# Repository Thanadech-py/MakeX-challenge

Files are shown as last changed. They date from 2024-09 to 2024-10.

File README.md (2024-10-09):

<h1 align="center">GravityShift</h1>
<h2>Code Of GravityShift Team</h2>
<p>
  This Respirotory is use for store and publish the code and CAD file of team for education and competion
</p> 

<h2>Teammate</h2>

- Thanadech Lapassirikul : Head-Programmer, Technicain, Main-Electical and Subport-Machanical
  
  Contact : [IG: Thanadech.py](https://www.instagram.com/thxncdzch.py/)
- Tanapat Pinnok : Head-Machanical, Subport-Electrical, Pilot and Quality Check

  Contact : [IG: zu.seven](https://www.instagram.com/zu.seven/)
- Natdanai duangraksa : Head-Designer and Subport-Machanical

  Contact : [IG: peanaatbattaa](https://www.instagram.com/nomchocolatemaiwan/)
- Pranutsma Khwanrueang : Suport-Designer, Copilot and Team Planer

  Contact : [IG: tgzee_](https://www.instagram.com/tgzee._/)

<h3>The link to the Document for MakeX Challenge Competition</h3>

- [MicroPython For NovaPI](https://github.com/Makeblock-official/micropython-api-doc/tree/master/docs/novapi/modules/modules).

- [Makeblock Officail Materials](https://grabcad.com/library/data-of-makeblock-parts-1).

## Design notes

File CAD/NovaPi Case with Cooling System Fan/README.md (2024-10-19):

<h1>NovaPi</h1>
The NovaPi is the main microcontroller that is use in MakeX Challenge Robotics Competition and also it came with the NovaPi Expansion board that we can connect the DC motor 12V 
so that we can control the actuators of the robot.
<h1>NovaPi Case</h1>
The NovaPi are sensitive to the conductive material such as copper, iron, gold, aluminum, and silver, so NovaPi Case is important to protect the NovaPi board.
<h1>Heat Problem</h1>
This sesson of MakeX Challenge Robotics Competition we face the problem that cause the NovaPi Expansion board the be broke and we see that the ATM Chip of the board is geting very hot.
So we design the new NovaPi Case that we can install the Brushless DC Fan to the case so that the fan can prevent the board the ve overheating.
<h1>The Design Of the NovaPi Case with Brushless DC Fan slot</h1>

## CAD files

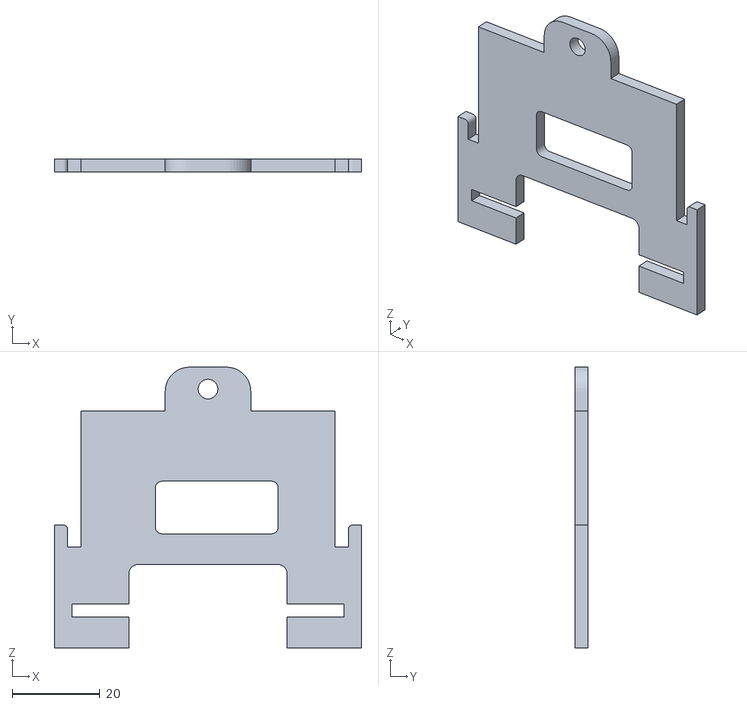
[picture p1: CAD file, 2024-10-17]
CAD/NovaPi Case with Cooling System Fan/NovaPi Case Blushless Motor Port and encoder motor port side_.stl
70.0 x 3.00 x 64.0

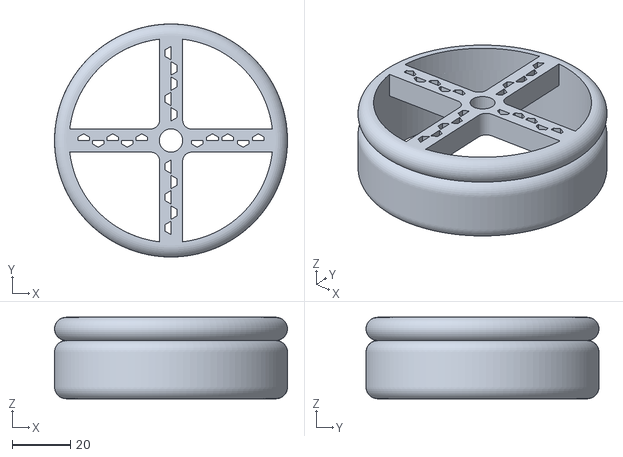
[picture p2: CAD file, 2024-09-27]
CAD/Shooter Wheels/bushless.stl
80.0 x 80.0 x 28.0

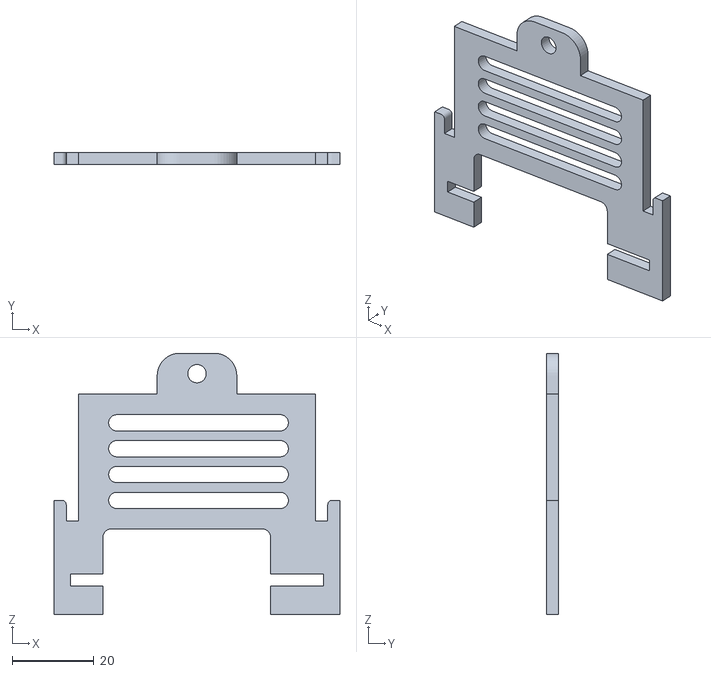
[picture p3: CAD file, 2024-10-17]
CAD/NovaPi Case with Cooling System Fan/NovaPi Case Upload and switch side_.stl
70.0 x 3.00 x 64.0

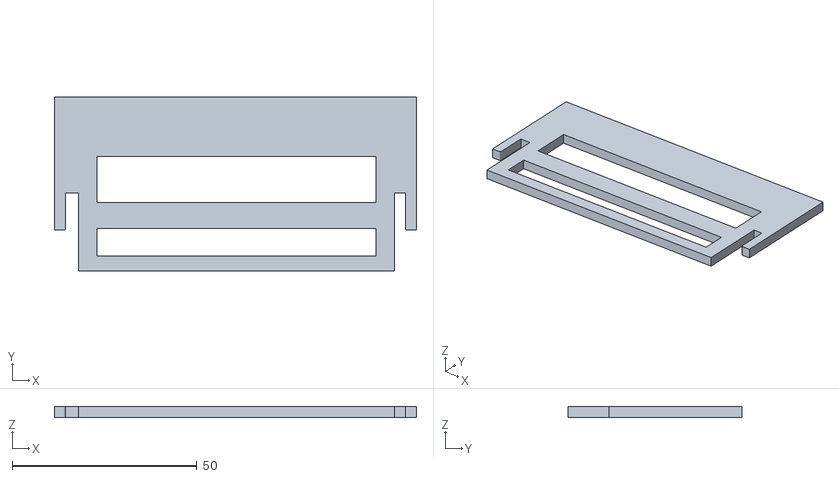
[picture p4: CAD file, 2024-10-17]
CAD/NovaPi Case with Cooling System Fan/NovaPi Case DC motor port and sensor port side_.stl
98.0 x 47.0 x 3.00

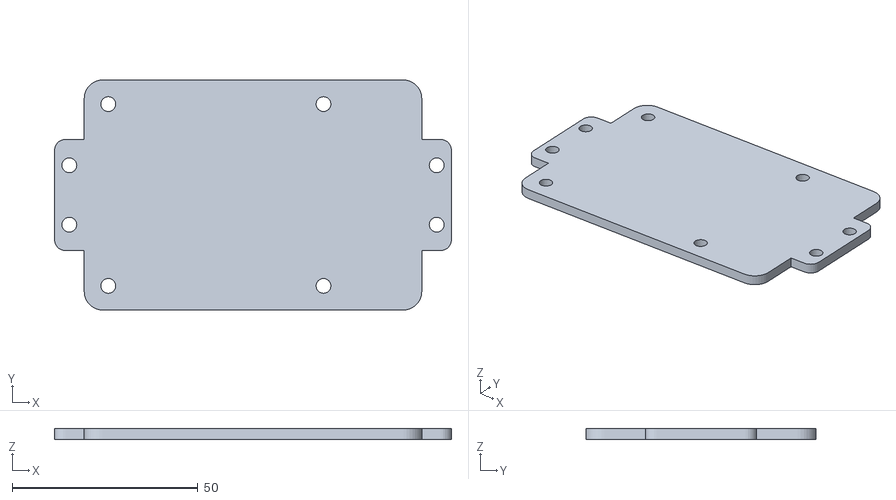
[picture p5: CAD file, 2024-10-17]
CAD/NovaPi Case with Cooling System Fan/NovaPi Case Base_link_.stl
107.0 x 62.0 x 3.00

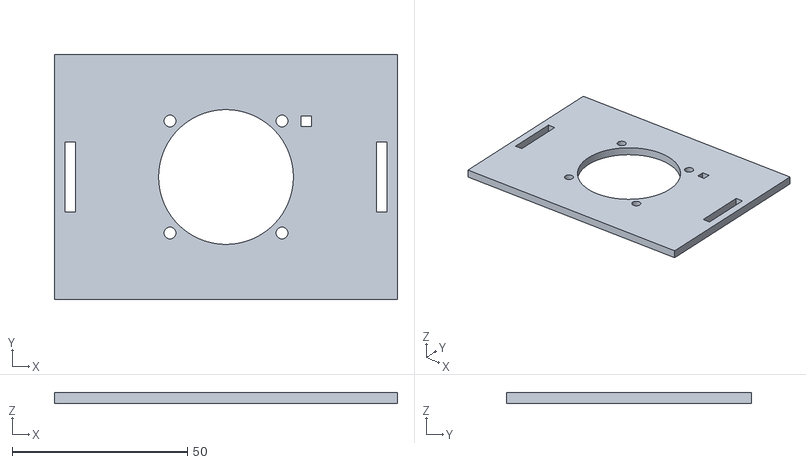
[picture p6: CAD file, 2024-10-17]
CAD/NovaPi Case with Cooling System Fan/NovaPi Case top_link_.stl
98.0 x 70.0 x 3.00

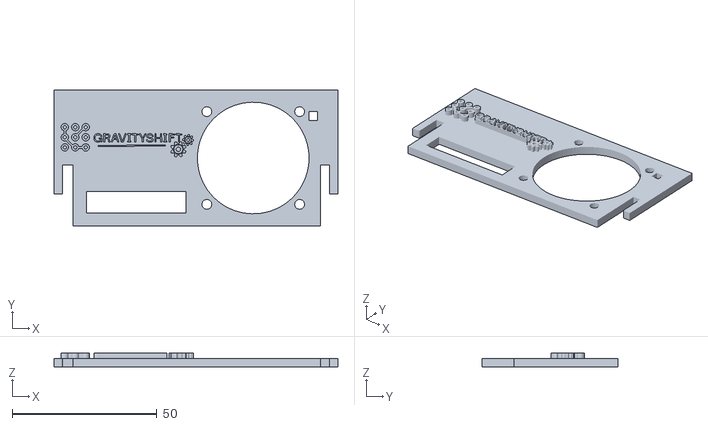
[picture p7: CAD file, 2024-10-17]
CAD/NovaPi Case with Cooling System Fan/NovaPi Case encoder motor M5, M6 side_.stl
98.0 x 47.0 x 5.00

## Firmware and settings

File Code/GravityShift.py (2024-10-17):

# Import necessary modules
import novapi
import time
import math
from mbuild.encoder_motor import encoder_motor_class
from mbuild import power_expand_board
from mbuild import gamepad
from mbuild.led_matrix import led_matrix_class
from mbuild.smart_camera import smart_camera_class
from mbuild.ranging_sensor import ranging_sensor_class
from mbuild.smartservo import smartservo_class
from mbuild import power_manage_module
import time

left_forward_wheel = encoder_motor_class("M2", "INDEX1")
right_forward_wheel = encoder_motor_class("M3", "INDEX1")
left_back_wheel = encoder_motor_class("M5", "INDEX1")
right_back_wheel = encoder_motor_class("M6", "INDEX1")

MAX_SPEED = 255
SPEED_MULTIPLIER = 2.1
PID_SPEED_MULTIPLIER = 0.6
BL_POWER = 100


class PID:
    def __init__(self, Kp,  Ki, Kd, setpoint=0):
        self.Kp = Kp  # Proportional gain
        self.Ki = Ki  # Integral gain
        self.Kd = Kd  # Derivative gain
        self.setpoint = setpoint  # Desired value (target)
        self.integral = 0  # Sum of errors over time
        self.previous_error = 0  # Previous error (used for derivative)

    def update(self, current_value):
        # Calculate the error (setpoint - current value)
        error = self.setpoint - current_value
        
        # Proportional term
        P = self.Kp * error
        
        # Integral term
        self.integral += error
        I = self.Ki * self.integral

        # Derivative term
        derivative = error - self.previous_error
        D = self.Kd * derivative

        # Calculate the output
        output = P + I + D

        # Save the current error for the next update
        self.previous_error = error

        return output

    def set_setpoint(self, setpoint):
        self.setpoint = setpoint
        self.integral = 0  # Reset the integral to avoid wind-up
        self.previous_error = 0  # Reset previous error to avoid a large derivative spike


class motors:
    
    def drive(lf: int, lb: int, rf: int, rb: int):
        left_back_wheel.set_speed(lb) # left back :DDDDD
        right_back_wheel.set_speed(-rb)  # RIGHT BACK  
        right_forward_wheel.set_speed(-(rf))      # RIGHT FORWARD
        left_forward_wheel.set_speed(lf)             # LEFT BACK
    
    def stop():
        motors.drive(0, 0, 0, 0)
        
class util:
    def restrict(val, minimum, maximum):
        return max(min(val, maximum), minimum)

class holonomic:    

    pids = {
        "lf": PID(Kp=1, Ki=0, Kd=0),
        "lb": PID(Kp=1, Ki=0, Kd=0),
        "rf": PID(Kp=0.9, Ki=0, Kd=0),
        "rb": PID(Kp=0.9, Ki=0, Kd=0),
    }

    # motor tune
    tune = {
        "fl": 0.9,
        "fr": 1,
        "bl": 0.8,
        "br": 1.2,
    }

    def drive(vx, vy, wL, deadzone=5, pid=False):
        global SPEED_MULTIPLIER, PID_SPEED_MULTIPLIER
        if math.fabs(vx) < math.fabs(deadzone):
            vx = 0
        if math.fabs(vy) < math.fabs(deadzone):
            vy = 0
        if math.fabs(wL) < math.fabs(deadzone):
            wL = 0

        # Ensure the correct speed multiplier
        multiplier = PID_SPEED_MULTIPLIER if pid else SPEED_MULTIPLIER
            
        # Calculation for the wheel speed
        vFL = (vx + (vy * 1.2) + wL) * multiplier
        vFR = (-(vx) + (vy * 1.2) - wL) * multiplier
        vBL = (-(vx) + (vy * 1.2) + wL) * multiplier
        vBR = (vx + (vy * 1.2) - wL) * multiplier
        
        # Sliding check to not interfere with the normal movement, incase of tuning specific power
        if math.fabs(vx) > math.fabs(vy) and vx > 0:
            vFL *= holonomic.tune["fl"] # หน้าซ้าย
            vFL *= holonomic.tune["fr"] # หน้าขวา
            vBL *= holonomic.tune["bl"] # หลังซ้าย
            vBR *= holonomic.tune["br"] # หลังขวา
        if pid:            
            # Left Forward
            holonomic.pids["lf"].set_setpoint(vFL)
            vFL = holonomic.pids["lf"].update(-left_forward_wheel.get_value("speed"))
            # Left Back
            holonomic.pids["lb"].set_setpoint(vBL)
            vBL = holonomic.pids["lb"].update(-left_back_wheel.get_value("speed"))
            # Right Forward
            holonomic.pids["rf"].set_setpoint(vFR)
            vFR = holonomic.pids["rf"].update(right_forward_wheel.get_value("speed"))
            # Right Back
            holonomic.pids["rb"].set_setpoint(vBR)
            vBR = holonomic.pids["rb"].update(right_back_wheel.get_value("speed"))

        # Velocity
        vFL = util.restrict(vFL, -MAX_SPEED, MAX_SPEED)
        vFR = util.restrict(vFR, -MAX_SPEED, MAX_SPEED)
        vBL = util.restrict(vBL, -MAX_SPEED, MAX_SPEED)
        vBR = util.restrict(vBR, -MAX_SPEED, MAX_SPEED)
        # Drive motor
        motors.drive(vFL, vBL, vFR, vBR)
        
    def move_forward(power):
        holonomic.drive(0, power, 0)
        
    def move_backward(power):
        holonomic.drive(0, -power, 0)
        
    def slide_right(power):
        holonomic.drive(power, 0, 0)
        
    def slide_left(power):
        holonomic.drive(-power, 0, 0)
        
    def turn_right(power):
        holonomic.drive(0, 0, power)
        
    def turn_left(power):
        holonomic.drive(0, 0, -power)

class Auto:
    def right():
        pass
    
    def left():
        pass
        

class dc_motor:
    # Default DC port
    dc_port = "DC1"
    # Default direction (not reversed)
    reverse = False
    
    # Initialize DC motor with a specific port
    def __init__(self, port: str) -> None:
        self.dc_port = port
        
    # Method to set the direction of the motor
    def set_reverse(self, rev: bool) -> None:
        self.reverse = rev
        
    # Method to turn on the DC motor
    def on(self) -> None:
        power = -100 if self.reverse else 100
        power_expand_board.set_power(self.dc_port, power)
        
    # Method to turn off the DC motor
    def off(self) -> None:
        power_expand_board.stop(self.dc_port)
        
class brushless_motor:
    # Default brushless motor port
    bl_port = "BL1"
    
    # Initialize brushless motor with a specific port
    def __init__(self, port: str) -> None:
        self.bl_port = port
        
    # Method to turn on the brushless motor
    def on(self) -> None:
        power_expand_board.set_power(self.bl_port, BL_POWER)
        
    # Method to turn off the brushless motor
    def off(self) -> None:
        power_expand_board.stop(self.bl_port)

      

class runtime:
    # Define control mode
    CTRL_MODE = 0
    
    # Robot state
    ENABLED = True
    def move_1():
        if math.fabs(gamepad.get_joystick("Lx")) > 20 or math.fabs(gamepad.get_joystick("Ly")) > 20 or math.fabs(gamepad.get_joystick("Rx")) > 20:
            holonomic.drive(-gamepad.get_joystick("Lx"), gamepad.get_joystick("Ly"), -gamepad.get_joystick("Rx"), pid=True)
        else:
            motors.drive(0,0,0,0)

    def move_2():
        if math.fabs(gamepad.get_joystick("Lx")) > 20 or math.fabs(gamepad.get_joystick("Ly")) > 20 or math.fabs(gamepad.get_joystick("Rx")) > 20:
            holonomic.drive(gamepad.get_joystick("Lx"), -gamepad.get_joystick("Ly"), -gamepad.get_joystick("Rx"), pid=True)
        else:
            motors.drive(0,0,0,0)
    def change_mode():
        if novapi.timer() > 0.9:
            entrance_feed.off()
            feeder.off()
            conveyer.off()
            if runtime.CTRL_MODE == 0:
                runtime.CTRL_MODE = 1
            else:
                runtime.CTRL_MODE = 0
            novapi.reset_timer()

class shoot_mode:
    # Method to control various robot functions based on button inputs
    def control_button():

        if gamepad.is_key_pressed("R2"):
            entrance_feed.set_reverse(True)
            entrance_feed.on()
            power_expand_board.set_power("DC7", 55) #feeder
            conveyer.set_reverse(False)
            conveyer.on()
        elif gamepad.is_key_pressed("L2"):
            entrance_feed.set_reverse(False)
            entrance_feed.on()
            power_expand_board.set_power("DC7", -55) #feeder
            conveyer.set_reverse(True)
            conveyer.on()
        if gamepad.is_key_pressed("L1"):
            entrance_feed.off()
            feeder.off()
            conveyer.off()
        if gamepad.is_key_pressed("R1"):
            bl_1.on()
            bl_2.on()
        else:
            bl_1.off()
            bl_2.off()
        if gamepad.is_key_pressed("≡"):
            laser.set_reverse(True)
            laser.on()
        elif gamepad.is_key_pressed("+"):
            laser.off()
        else:
            pass
        if gamepad.is_key_pressed("N3"):
            entrance_feed.set_reverse(False)
            entrance_feed.on()
            power_expand_board.set_power("DC7", -65) #feeder
            conveyer.set_reverse(False)
            conveyer.on()
        elif gamepad.is_key_pressed("N2"):
            entrance_feed.set_reverse(True)
            entrance_feed.on()
            power_expand_board.set_power("DC7", 65) #feeder
            conveyer.set_reverse(True)
            conveyer.on()
        elif gamepad.is_key_pressed("N2") or gamepad.is_key_pressed("N3") == False:
            entrance_feed.off()
            feeder.off()
            conveyer.off()
        #shooter_angle control
        if gamepad.is_key_pressed("Up"):
            shooter.move(5, 10)
        elif gamepad.is_key_pressed("Down"):
            shooter.move(-5, 10)
        else:
            pass
 
class gripper_mode:
    # Method to control various robot functions based on button inputs
    def control_button():
        if gamepad.is_key_pressed("N2"):
            lift.set_power(-75)
        elif gamepad.is_key_pressed("N3"):
            lift.set_power(75)
        else:
            lift.set_speed(0)
        if gamepad.is_key_pressed("N1"):
            gripper1.set_reverse(False)
            gripper2.set_reverse(False)
            gripper1.on()
            gripper2.on()

        elif gamepad.is_key_pressed("N4"):
            gripper1.set_reverse(True)
            gripper2.set_reverse(True)
            gripper1.on()
            gripper2.on()
        else:
            gripper1.off()
            gripper2.off()
        

# Instantiate DC motors
lift = encoder_motor_class("M4", "INDEX1") # using encoder for spacific position of lift functions
gripper2 = dc_motor("DC2")
gripper1 = dc_motor("DC1")
conveyer = dc_motor("DC5")
entrance_feed = dc_motor("DC6")
feeder = dc_motor("DC7")
bl_1 = brushless_motor("BL1")
bl_2 = brushless_motor("BL2")
shooter = smartservo_class("M1", "INDEX1") # only for angles
laser = dc_motor("DC8")

while True:
    
    if power_manage_module.is_auto_mode():
        Auto.left()
    else:
        if gamepad.is_key_pressed("L2") and gamepad.is_key_pressed("R2"):
            runtime.change_mode()
        else:
            if runtime.CTRL_MODE == 0:
                shoot_mode.control_button()
                runtime.move_1()
            else:
                gripper_mode.control_button()
                runtime.move_2()

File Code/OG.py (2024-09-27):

import novapi
from mbuild import gamepad 
from mbuild.encoder_motor import encoder_motor_class
from mbuild.servo_driver import servo_driver_class
from mbuild import power_expand_board
from mbuild.smartservo import smartservo_class
from mbuild import power_manage_module
from mbuild.ranging_sensor import ranging_sensor_class
import math

smartservo_1 = smartservo_class("M6", "INDEX1")

# def auto():
#         #define ranging_sensor and set the distance varable
#         ranging_sensor_1 = ranging_sensor_class("PORT1", "INDEX1") 
#         cm = ranging_sensor_1.get_distance()

#         #condition of the ranging_sensor
#         if(cm == 5):
#                 pass
#         else:
#                 pass

#encode motor
def active_motor(motor, type, speed=65):
    strMotor = "M{}".format(motor)
    strP = speed
    if(type == 'f'):
        if(motor == 2):
           encoder_motor_class(strMotor, "INDEX1").set_power(-strP)
        elif(motor == 3):
           encoder_motor_class(strMotor, "INDEX1").set_power(-strP)
        elif(motor == 4):
           encoder_motor_class(strMotor, "INDEX1").set_power(strP)
        elif(motor == 5):
           encoder_motor_class(strMotor, "INDEX1").set_power(strP)
    elif(type == 'b'):
        if(motor == 2):
           encoder_motor_class(strMotor, "INDEX1").set_power(strP)
        elif(motor == 3):
           encoder_motor_class(strMotor, "INDEX1").set_power(strP)
        elif(motor == 4):
           encoder_motor_class(strMotor, "INDEX1").set_power(-strP)
        elif(motor == 5):
           encoder_motor_class(strMotor, "INDEX1").set_power(-strP)
    elif(type == 'off'):
        encoder_motor_class(strMotor, "INDEX1").set_power(0)

def movement():
        left = gamepad.is_key_pressed("Left")
        right = gamepad.is_key_pressed("Right")
        up = gamepad.is_key_pressed("Up")
        down = gamepad.is_key_pressed("Down")
        if(gamepad.get_joystick("Lx") == -100):
                active_motor(2, 'b')
                active_motor(5, 'f')
                active_motor(3, 'f')
                active_motor(4, 'b')
        elif(gamepad.get_joystick("Lx") == 100):
                active_motor(2, 'f')
                active_motor(5, 'b')
                active_motor(3, 'b')
                active_motor(4, 'f')
        elif(up and down == False and right == False and left == False):
                active_motor(2, 'f')
                active_motor(5, 'f')
                active_motor(3, 'f')
                active_motor(4, 'f')
        elif(down and up == False and right == False and left == False):
                active_motor(2, 'b')
                active_motor(5, 'b')
                active_motor(3, 'b')
                active_motor(4, 'b')
        elif(left and up and right == False and down == False):
                active_motor(2, 'off')
                active_motor(5, 'f')
                active_motor(3, 'f')
                active_motor(4, 'off')
        elif(right and up and left == False and down == False):
                active_motor(2, 'f')
                active_motor(5, 'off')
                active_motor(3, 'off')
                active_motor(4, 'f')
        elif(left and down and right == False and up == False):
                active_motor(2, 'off')
                active_motor(5, 'b')
                active_motor(3, 'b')
                active_motor(4, 'off')
        elif(right and down and left == False and up == False):
                active_motor(2, 'b')
                active_motor(5, 'off')
                active_motor(3, 'off')
                active_motor(4, 'b')
        elif(right and down == False and left == False and up == False):
                active_motor(4, 'f')    #expand 
                active_motor(5, 'f')   
                active_motor(2, 'b')    #extends
                active_motor(3, 'b')
        elif(left and down == False and up == False and right == False):
                active_motor(4, 'b')
                active_motor(5, 'b')   
                active_motor(2, 'f')
                active_motor(3, 'f')
        else:
                active_motor(2, 'off')
                active_motor(5, 'off')
                active_motor(3, 'off')
                active_motor(4, 'off')

def feed_control():
        if(gamepad.get_joystick("Ry") == 100):
                power_expand_board.set_power("DC2", 100)
        elif(gamepad.get_joystick("Ry") == -100):
                power_expand_board.set_power("DC2", -100)
        else:
                power_expand_board.set_power("DC2", 0)

def feed_blushless():
        if(gamepad.get_joystick("Rx") == 100):
                power_expand_board.set_power("DC3", -100)
        elif(gamepad.get_joystick("Rx") == -100):
                power_expand_board.set_power("DC3", 100)
        else:
                power_expand_board.set_power("DC3", 0)



Front_feed = False
Laser = False
RY = gamepad.get_joystick("Ry")
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

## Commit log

2024-06-17 Update MakeX Challeng 2024.py
    add feed_blushless function and condition that control servo motor to set the angle of blushless motor
2024-06-20 Update MakeX Challeng 2024.py
    Decrease front_feed motor speed and change the control of slide from button to joystick
2024-06-21 Update MakeX Challeng 2024.py
    add condition to control gripper that will grip
2024-09-27 Update MakeX Challeng 2024.py
    Add PID movement control and change the control of the feed system also change the shooter angle control from DC_motor to servo
2024-09-30 Update GravityShift.py
    Change the wheels port and change the control of shooter angle by using up and down button
2024-10-01 Update GravityShift.py
    Change the runtime change mode function and change the condition for moving servo
2024-10-02 Update GravityShift.py
    Change the direction of entrance_feed and create mode of movement for gripper and shooting
2024-10-12 Update GravityShift.py
    Change lift from dc_motor to encoder motor for more specific position of lift function
2024-10-17 Rename CAD/bushless.stl to CAD/Shooter Wheels/bushless.stl
    [bushless.stl]
